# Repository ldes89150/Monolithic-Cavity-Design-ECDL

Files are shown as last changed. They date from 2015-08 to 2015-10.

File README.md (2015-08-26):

# Monolisthic-Cavity-Design-ECDL

## Part Serial numbers
- Grating: [GH13-18V](http://www.thorlabs.de/thorproduct.cfm?partnumber=GH13-18V)
- Collimation Package: [LT110P-B](http://www.thorlabs.de/thorproduct.cfm?partnumber=LT110P-B), [LT220P-B](http://www.thorlabs.de/thorproduct.cfm?partnumber=LT220P-B)
- Socket: [STO5S](http://www.thorlabs.de/thorproduct.cfm?partnumber=STO5S)

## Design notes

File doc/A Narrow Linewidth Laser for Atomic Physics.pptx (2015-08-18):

## A Narrow Linewidth Laser for Atomic Physics

Chung You Shih
Advisor: Dr. Ming-Shien Chang

## Outline

Introduction
Design
Measurement
Frequency locking
Conclusion & Future Work

## Introduction to ECDL

What is ?

E

C

D

L

xternal

avity

iode

aser

## Diode Laser for Atomic Physics

Pros
Cons
high efficiency
compact
inexpensive
wider linewidth
almost maintenance-free
Very stable

## External Cavity

- select central frequency

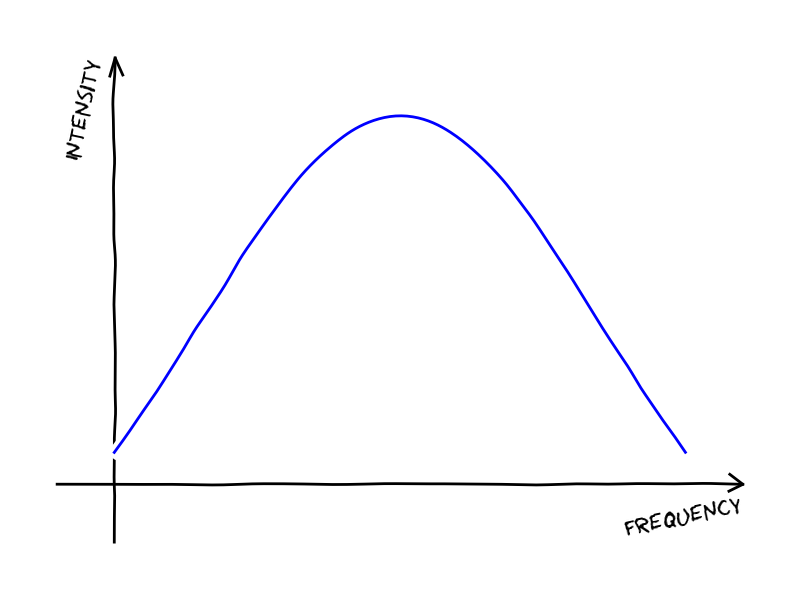
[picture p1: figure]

Δν_(laser)

ν

Narrow laser linewidth

Surface Grating

Volume Holography Grating

Color Filter

Schawlow-Townes Linewidth:
Δν_(laser) =(hν(1+α^2 )l_(tot) T_(oc))/(4πT_(rt)^2 P_(out))

## Purpose – Cold Atom Physics

- Probe atoms
- laser cooling
- Coherent control on atomic states
- optical trap (detuned)

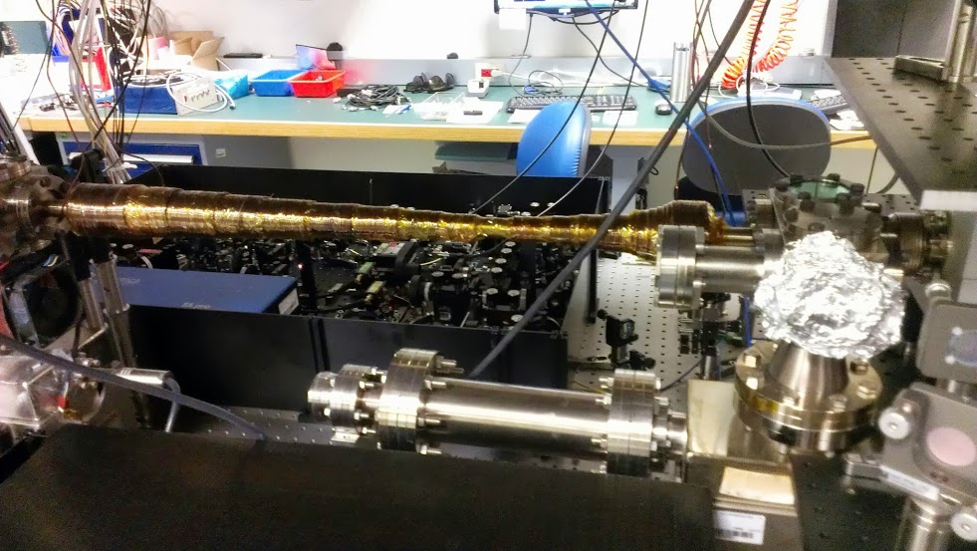
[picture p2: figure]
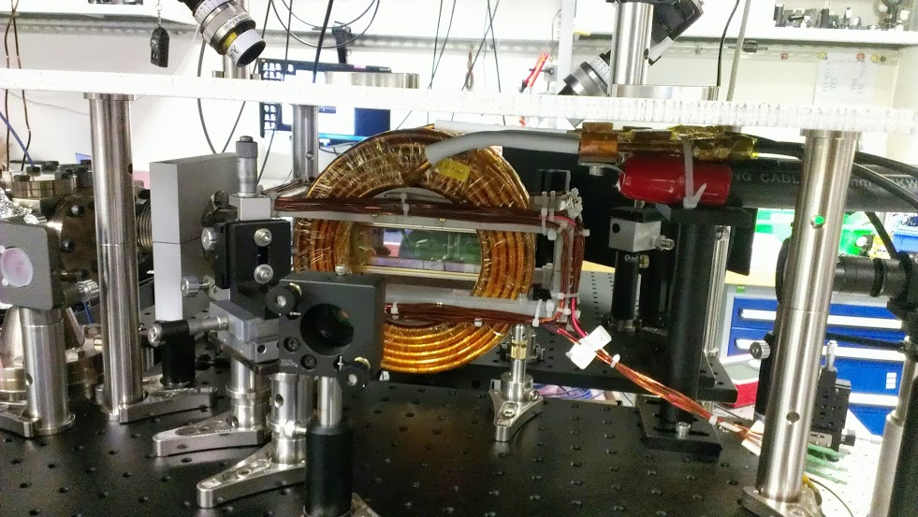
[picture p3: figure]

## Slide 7

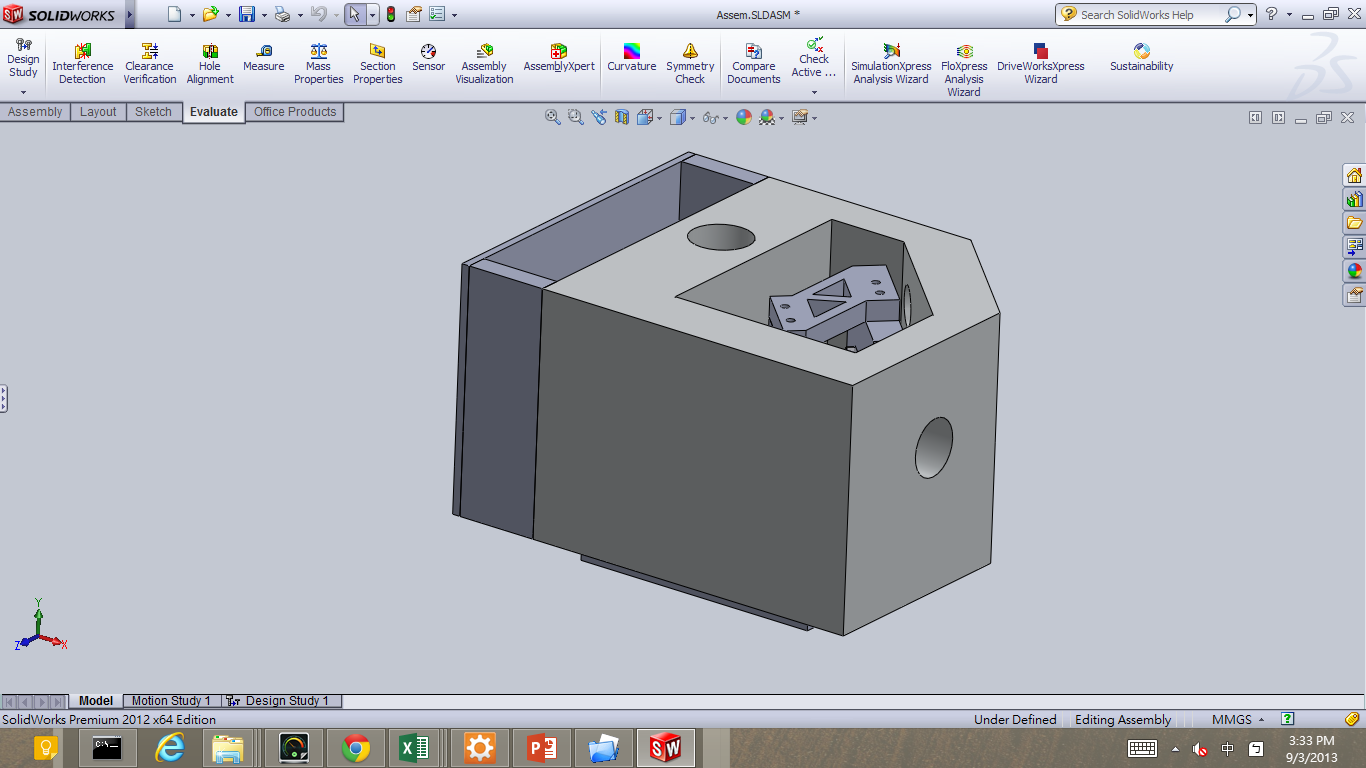
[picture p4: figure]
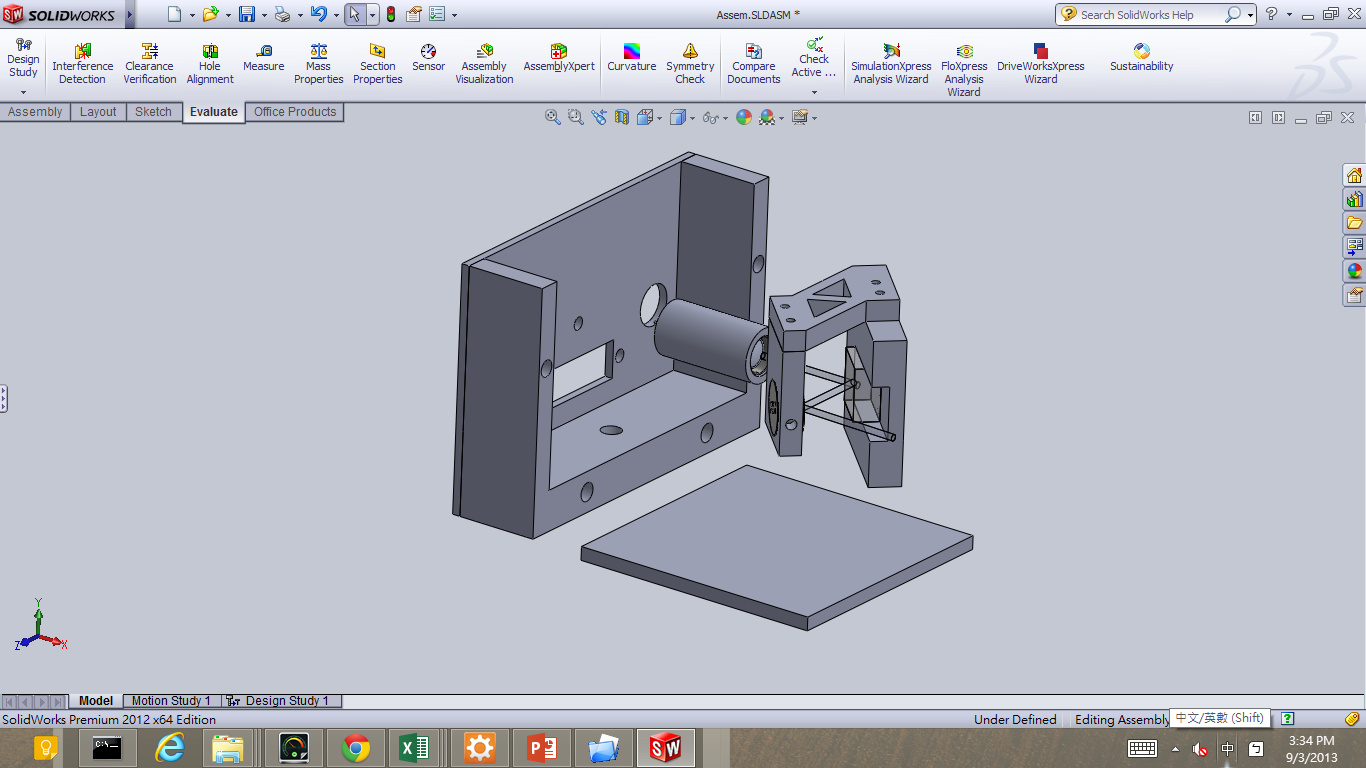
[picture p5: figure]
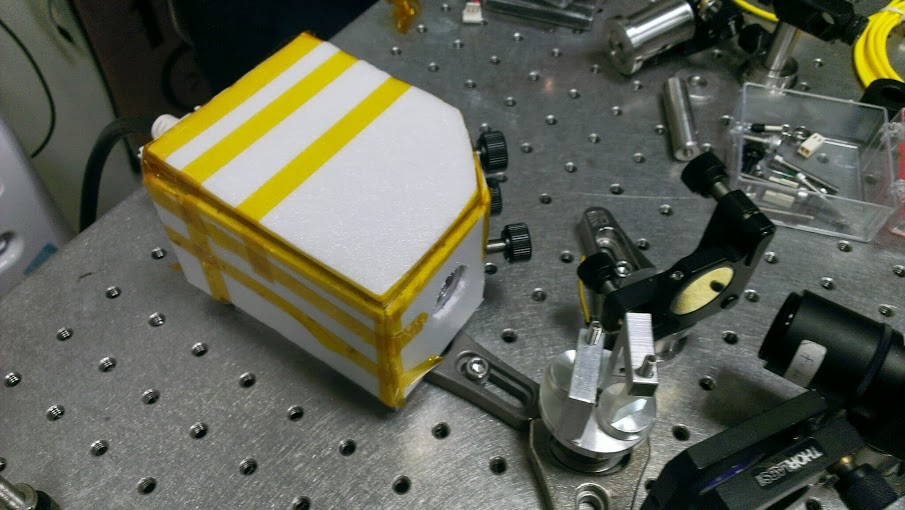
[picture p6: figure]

Idea: Monolithic cavity design
1.high heat capacity
2.good heat conductivity
- temperature control
Mechanical Stability

## Littrow configuration

The grating is always parallel to the mirror.
- No angle shift
Δx=2lΔθ

- Grating equation:
- d(sinα+sinβ)=mλ

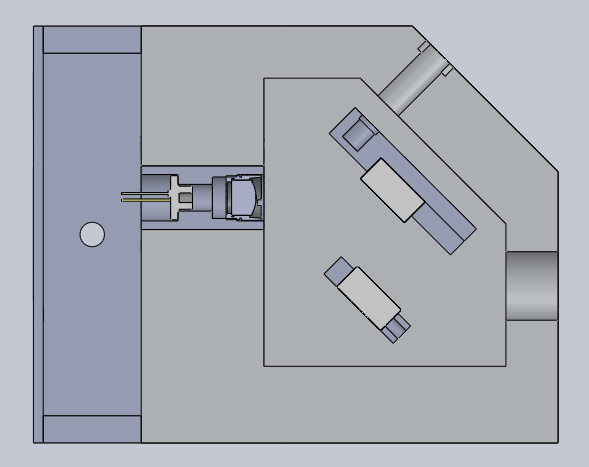
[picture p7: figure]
畫面剪輯

m=1
optical feed back

m=0
beam output

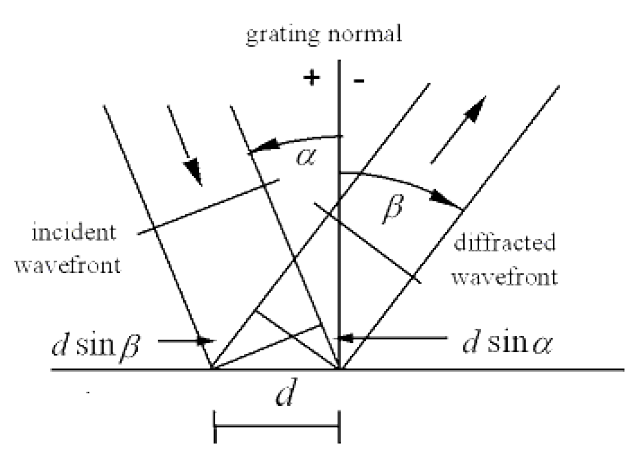
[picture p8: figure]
畫面剪輯

m=1, α=β for optical feed back
2dsinα=λ

2×(1mm)/1800×sinα=1×780.25nm
α=44.606°

m=0 for beam output
α=−β (law of reflection)

## Threshold Current

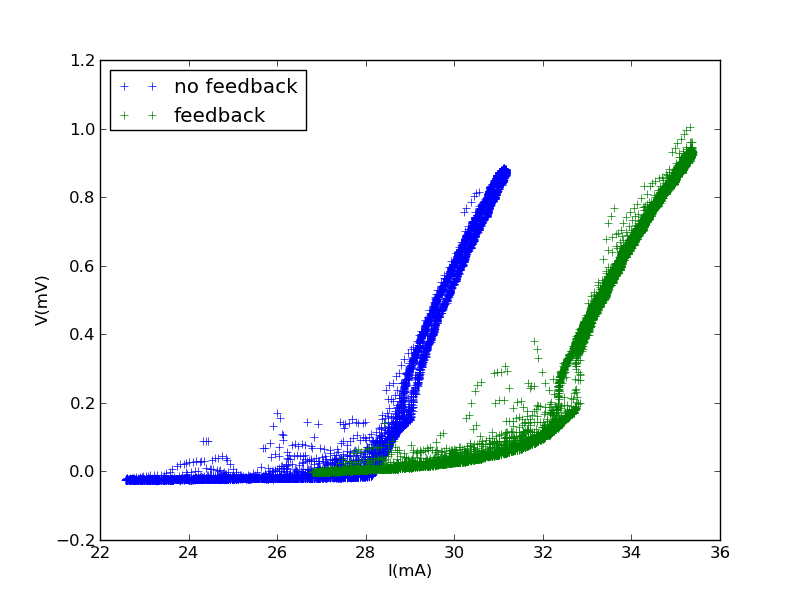
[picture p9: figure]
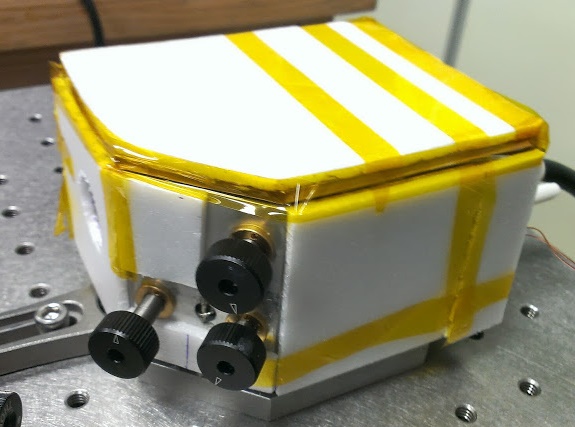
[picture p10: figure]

## Free running

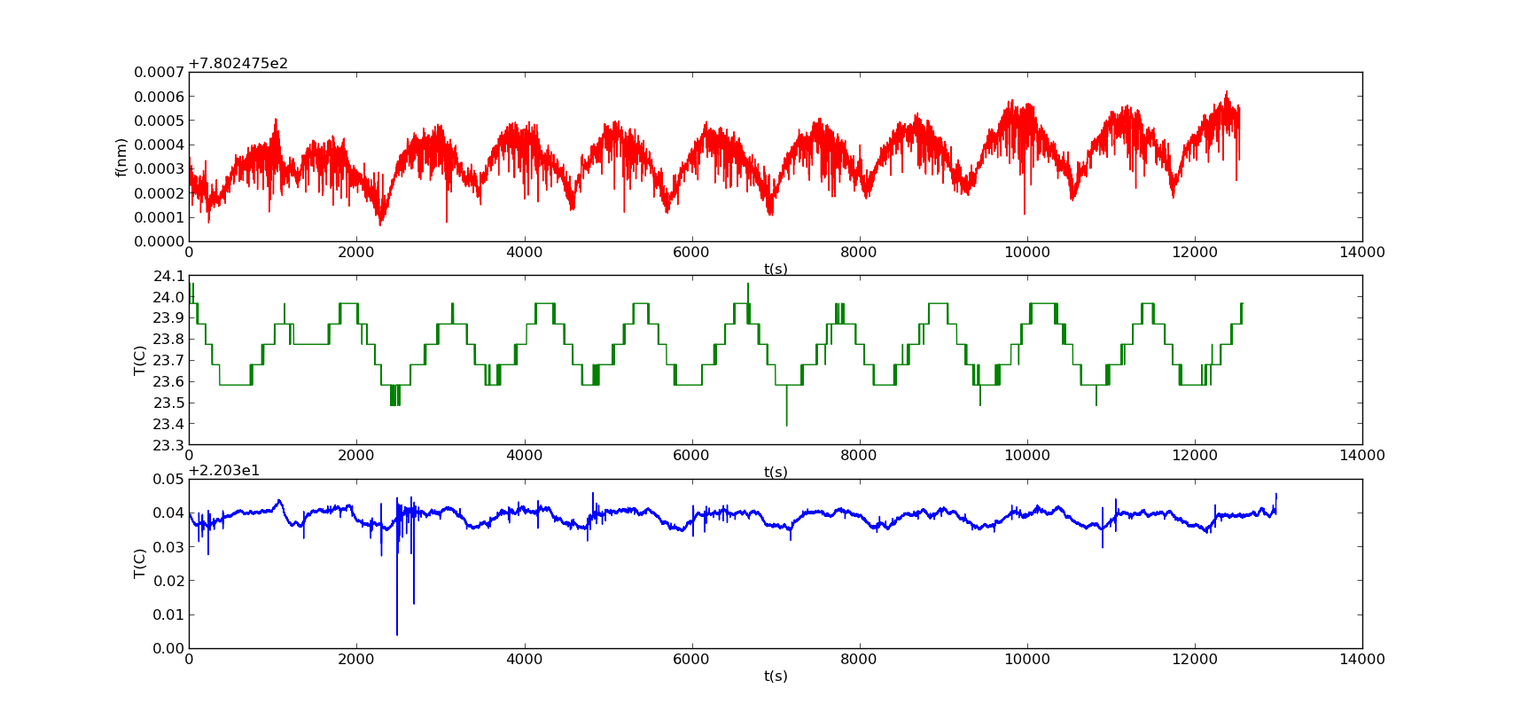
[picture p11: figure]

the same period

<10mk

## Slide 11

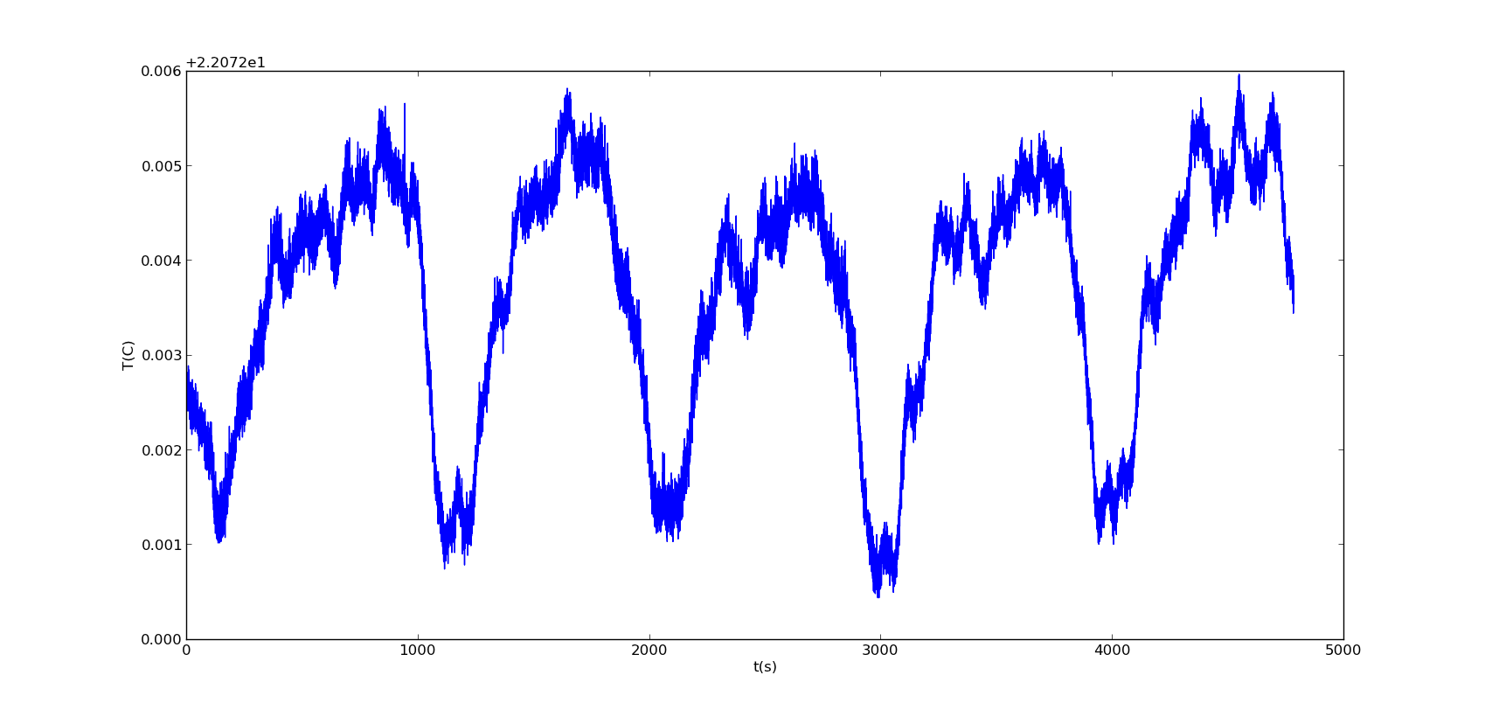
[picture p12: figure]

<5mk

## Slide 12

Lock-in-Amplifier

PD

PBS

250kHz

PID

λ /2

optical isolator

coil

ECDL

wave meter

λ /4

vapor cell

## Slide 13

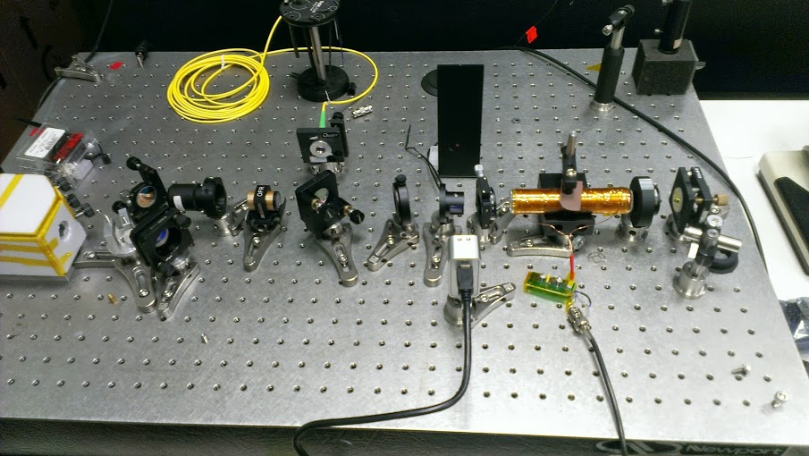
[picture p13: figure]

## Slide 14

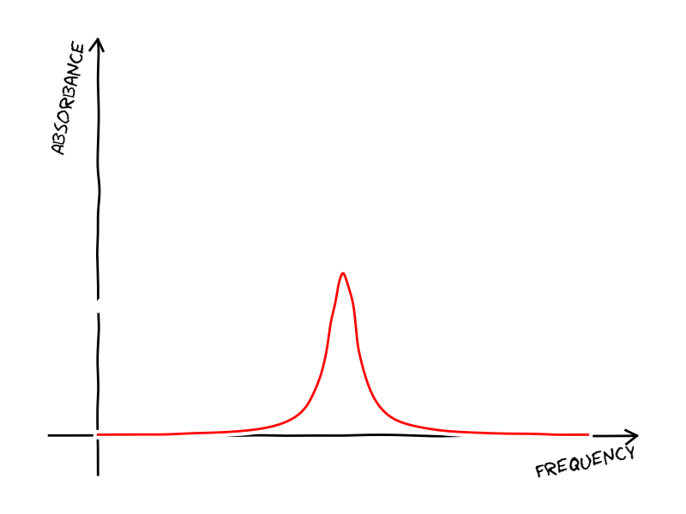
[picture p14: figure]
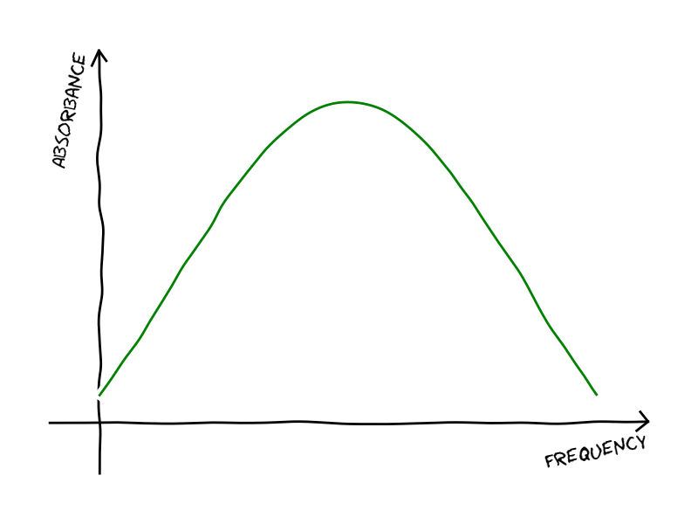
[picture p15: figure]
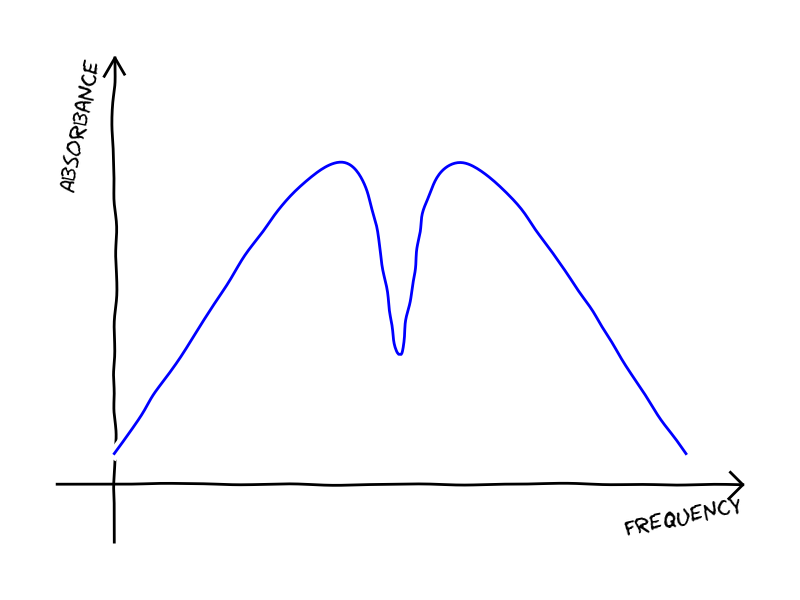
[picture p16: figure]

vz=0

Nature
(Lorentzian)

Negative

Doppler Borden
(Gaussian)

Positive

vapor cell

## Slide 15

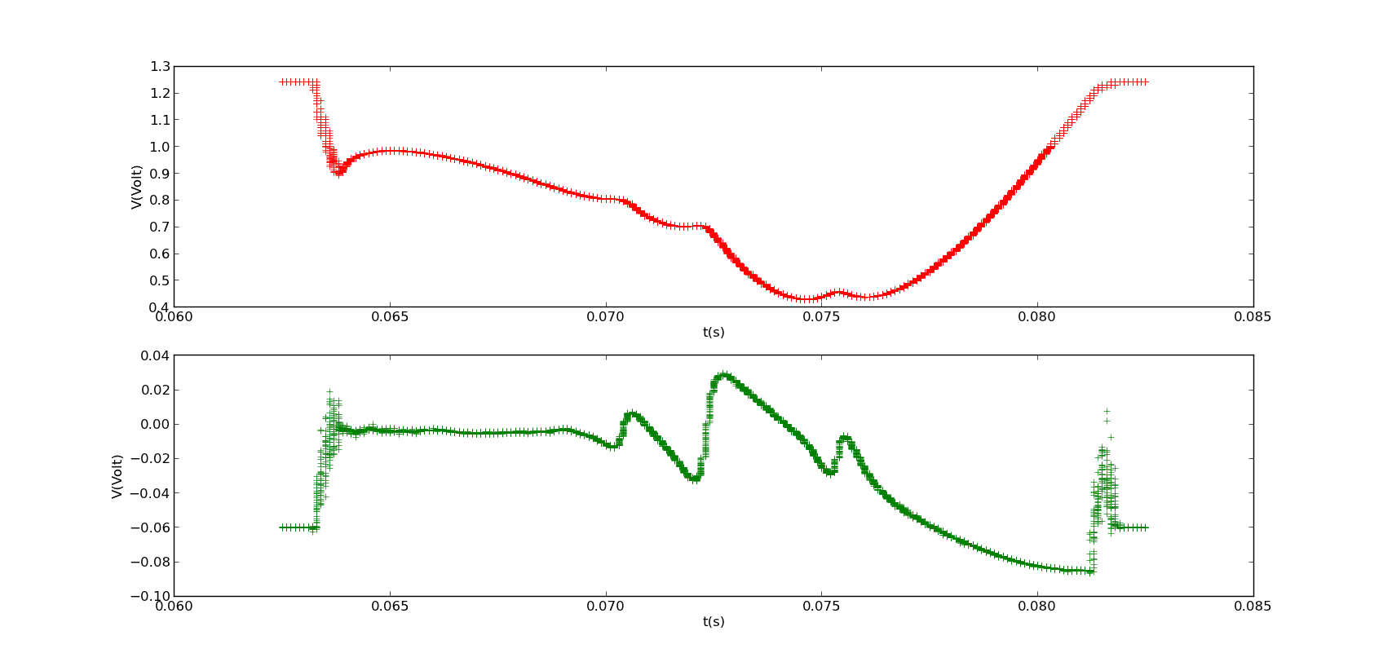
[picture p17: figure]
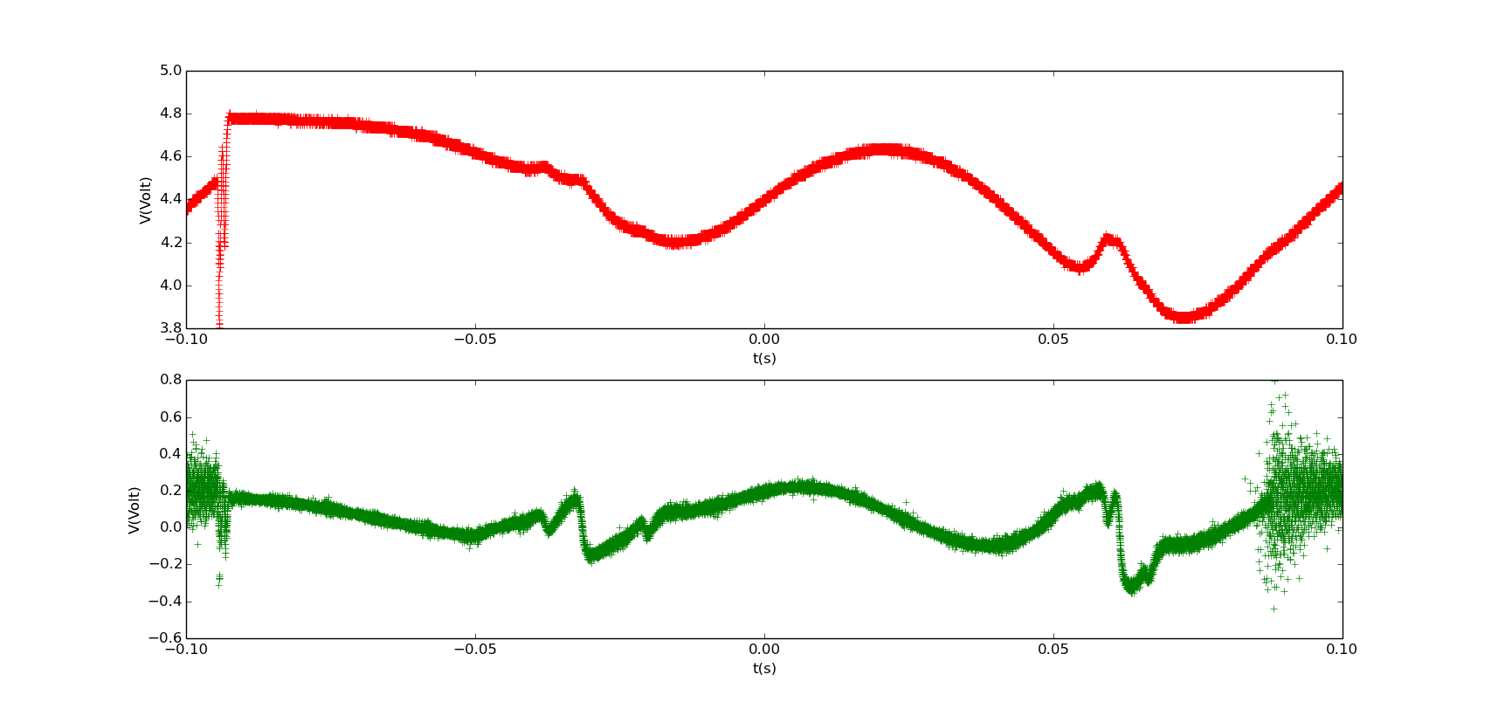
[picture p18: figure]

Rb-87 D2 Line

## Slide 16

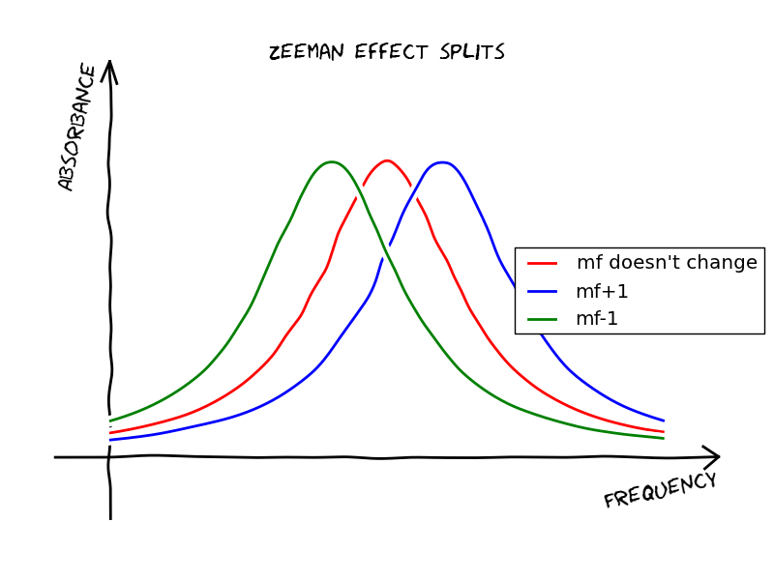
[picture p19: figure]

vapor cell

Linear

λ /4

Circular

degenerate
→2F+1 sublevels

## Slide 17

- frequency:ν=ν_L +ν_m cosωt
- V(ν_L +ν_m cosωt)≈V(ν_L )+((∂V)/(∂ν))_(ν_L) ν_m cosωt
- Lock-in Amplifier: Multiplier + Low Pass Filter
- ∫ (V(ν_L )+((∂V)/(∂ν))_(ν_L) ν_m cosωt)×Kcosωt dt=K/2((∂V)/(∂ν))_(ν_L) ν_m

Lock-in-Amplifier

PID

250kHz

vapor cell

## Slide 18

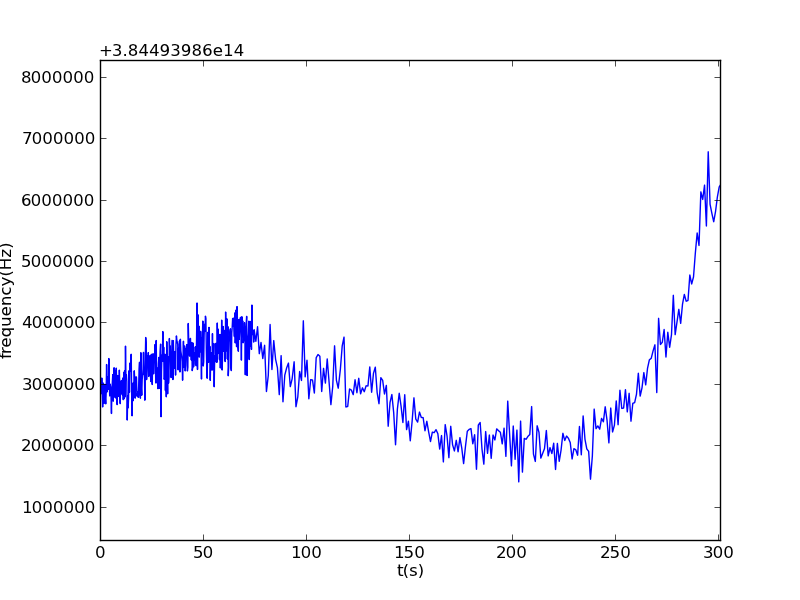
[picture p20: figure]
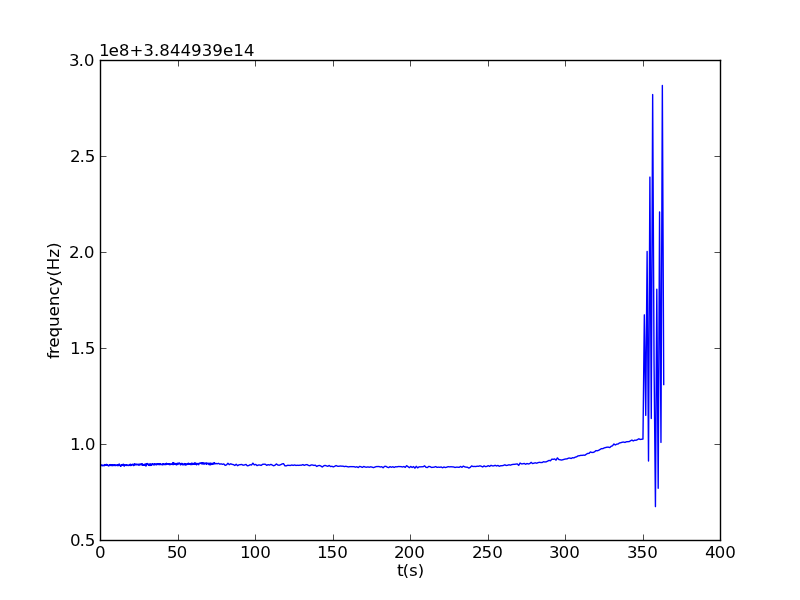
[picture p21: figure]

<3MHz

## Conclusion

- Monolithic cavity design
- Laser stability study
- Saturation spectroscopy
- Laser frequency stabilization

## Future Work

- Linewidth measurement
- Frequency locking optimization
- Laser cooling

## Acknowledgement

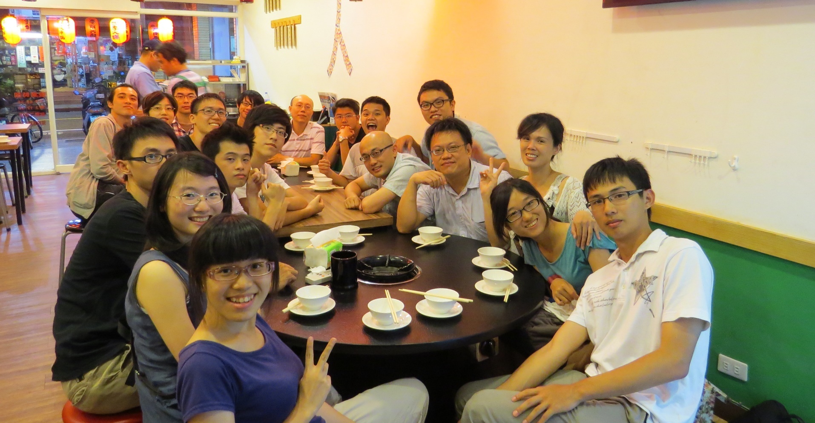
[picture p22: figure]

Lab 107 &
Dr. Ming-Shien Chang

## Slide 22

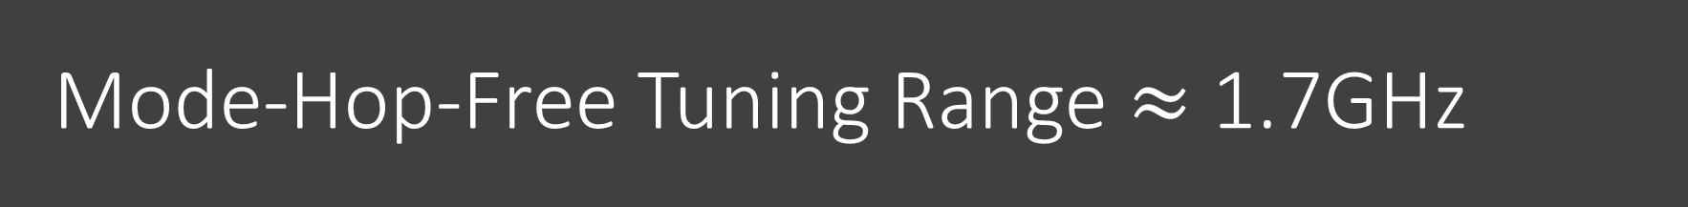
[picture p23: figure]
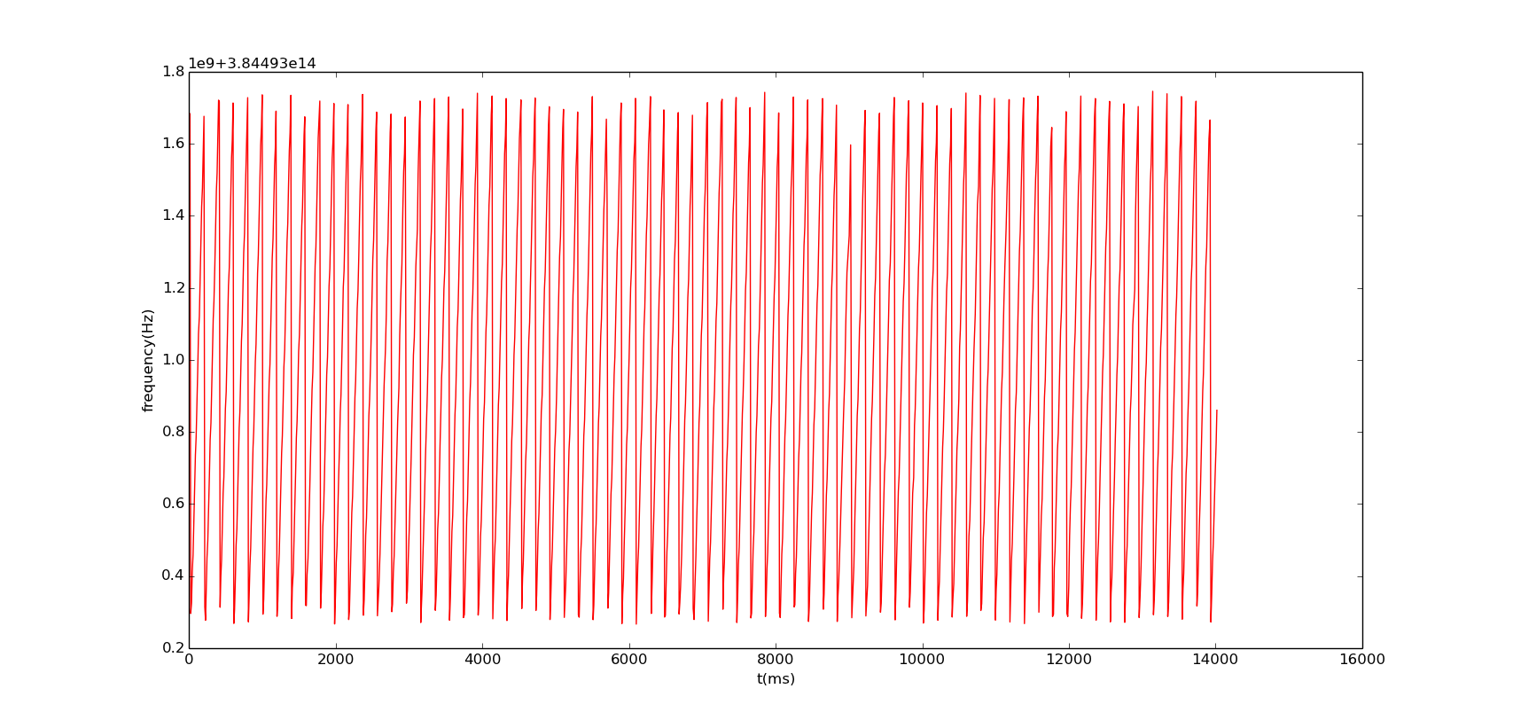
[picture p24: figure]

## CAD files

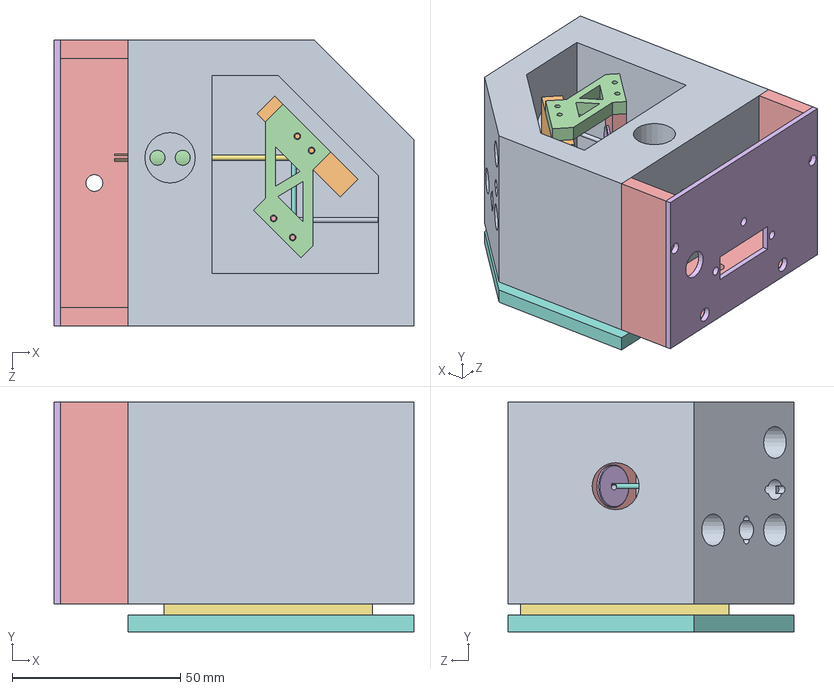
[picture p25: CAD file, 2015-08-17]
Assem.SLDASM
107.0 x 68.3 x 85.0 mm
mirror mount part
GR13-1208-Solidworks
arm part1
arm part2
BB05-E03-Solidworks
laser1
laser2
laser3
diode
C220TME-B-Solidworks
colimation tube final ver2
back
plate
TEC

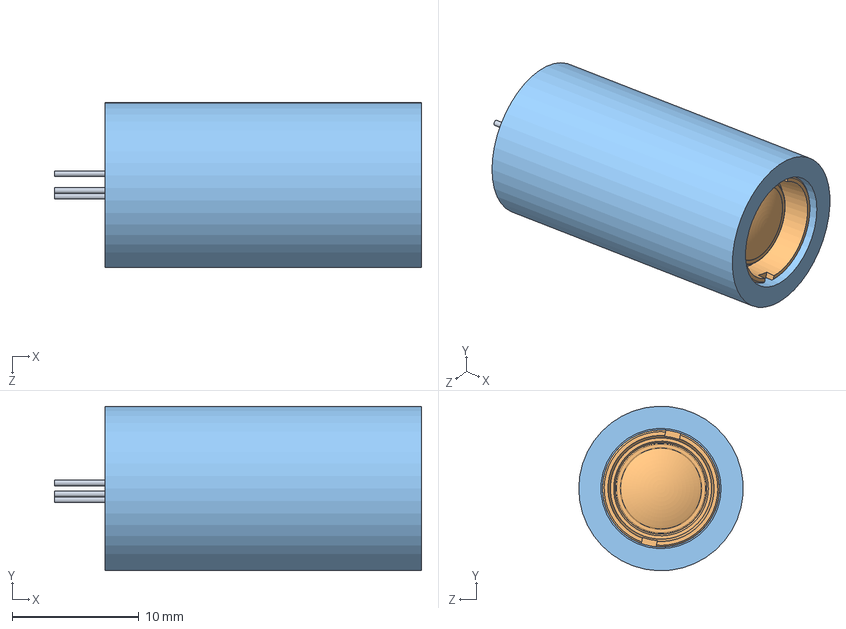
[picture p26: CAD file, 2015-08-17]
colimation tube assembly final.SLDASM
29.0 x 13.0 x 13.0 mm
diode
C220TME-B-Solidworks
colimation tube final ver2

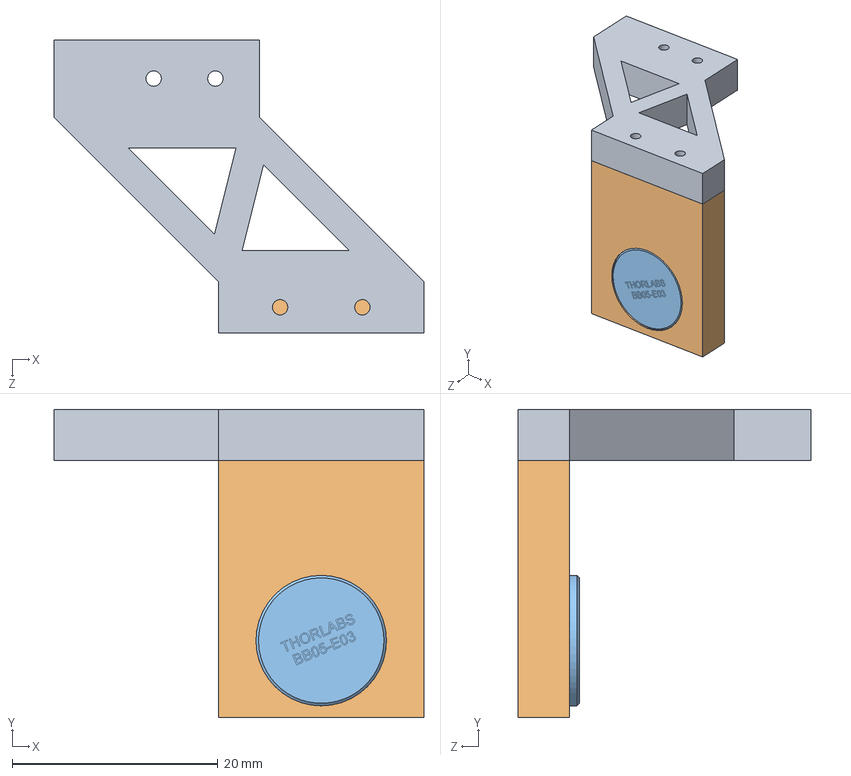
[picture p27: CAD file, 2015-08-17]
arm.SLDASM
36.0 x 30.0 x 28.5 mm
arm part1
arm part2
BB05-E03-Solidworks

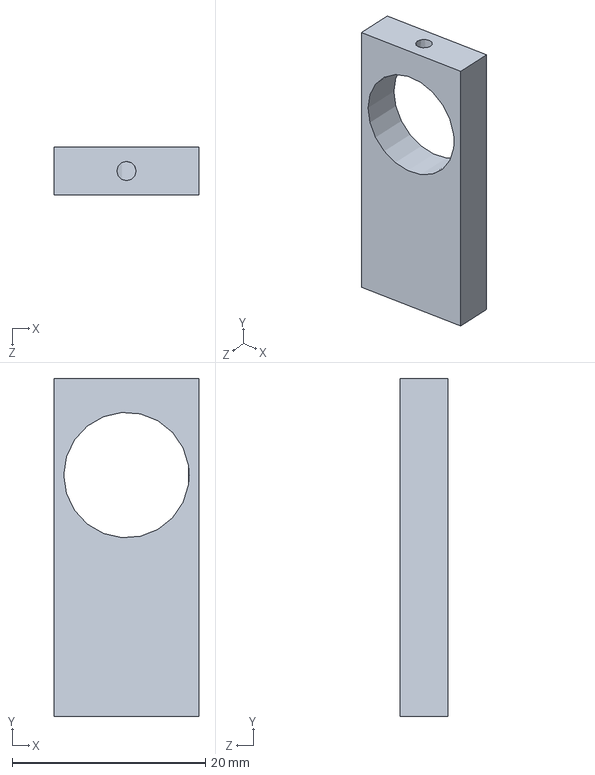
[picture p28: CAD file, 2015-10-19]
filter holder.SLDPRT
15.0 x 35.0 x 5.00 mm

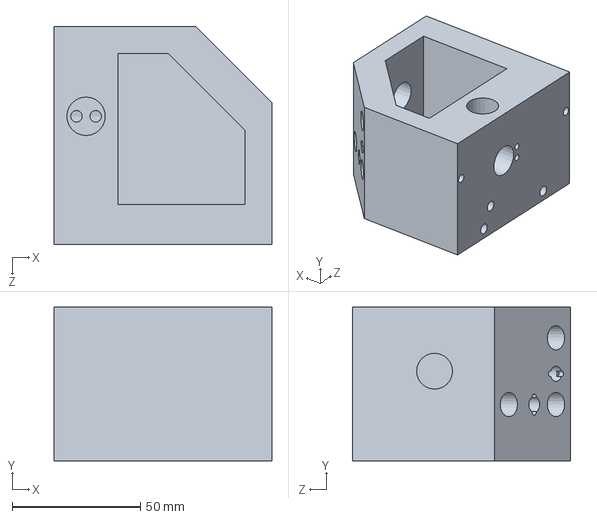
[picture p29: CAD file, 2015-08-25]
box 1.5.SLDPRT
85.0 x 60.0 x 85.0 mm

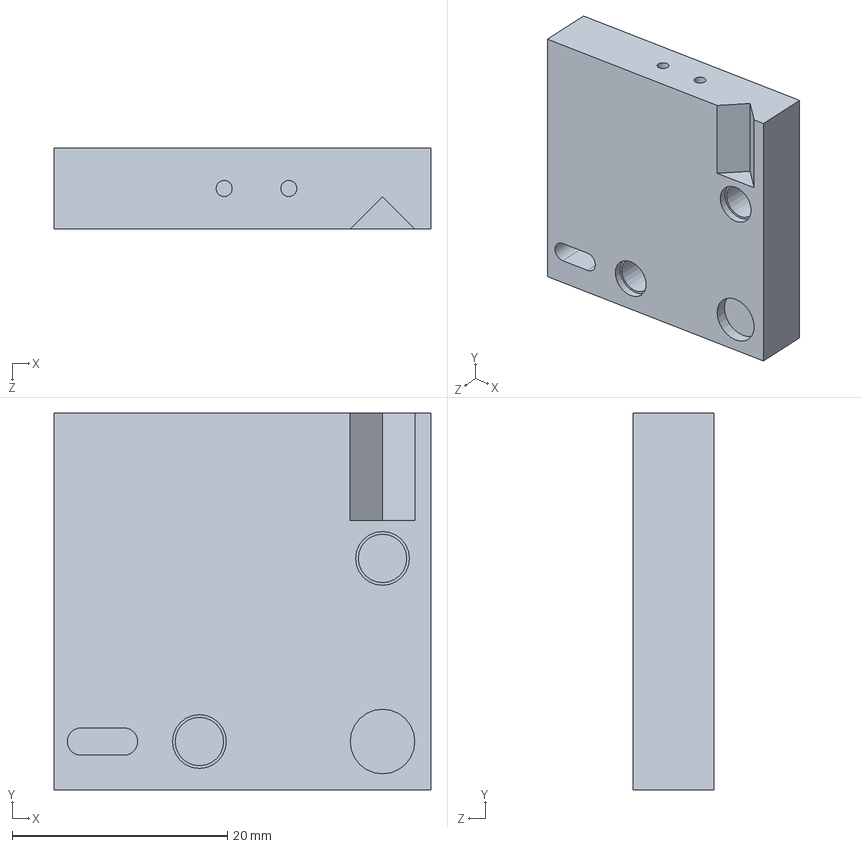
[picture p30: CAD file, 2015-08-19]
mirror mount part.SLDPRT
35.0 x 35.0 x 7.50 mm

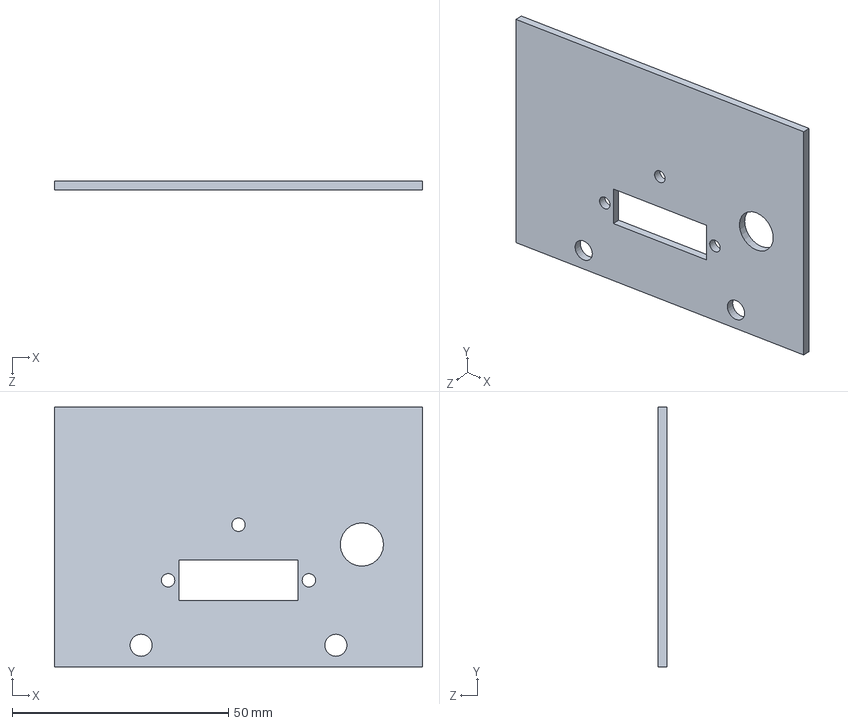
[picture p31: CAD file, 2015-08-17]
plate.SLDPRT
85.0 x 60.0 x 2.00 mm

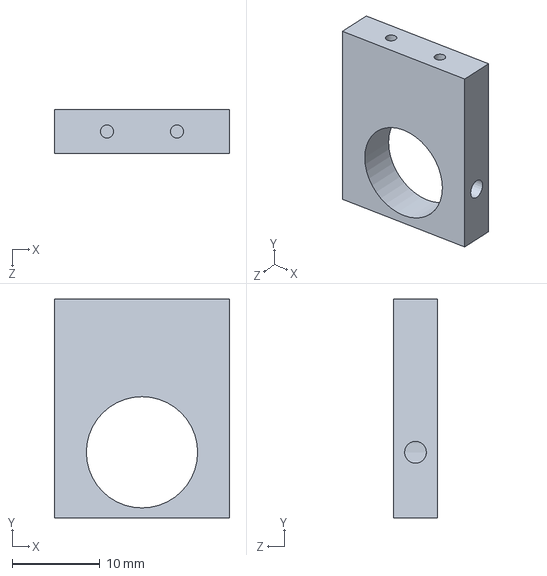
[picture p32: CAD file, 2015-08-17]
arm part2.SLDPRT
20.0 x 25.0 x 5.00 mm

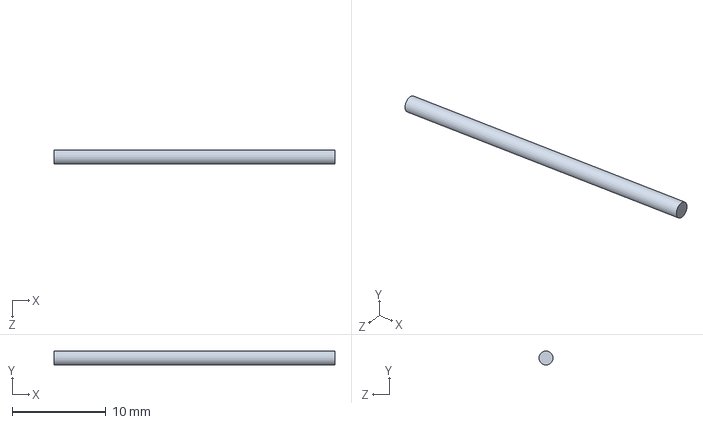
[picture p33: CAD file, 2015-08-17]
laser2.SLDPRT
30.0 x 1.50 x 1.50 mm

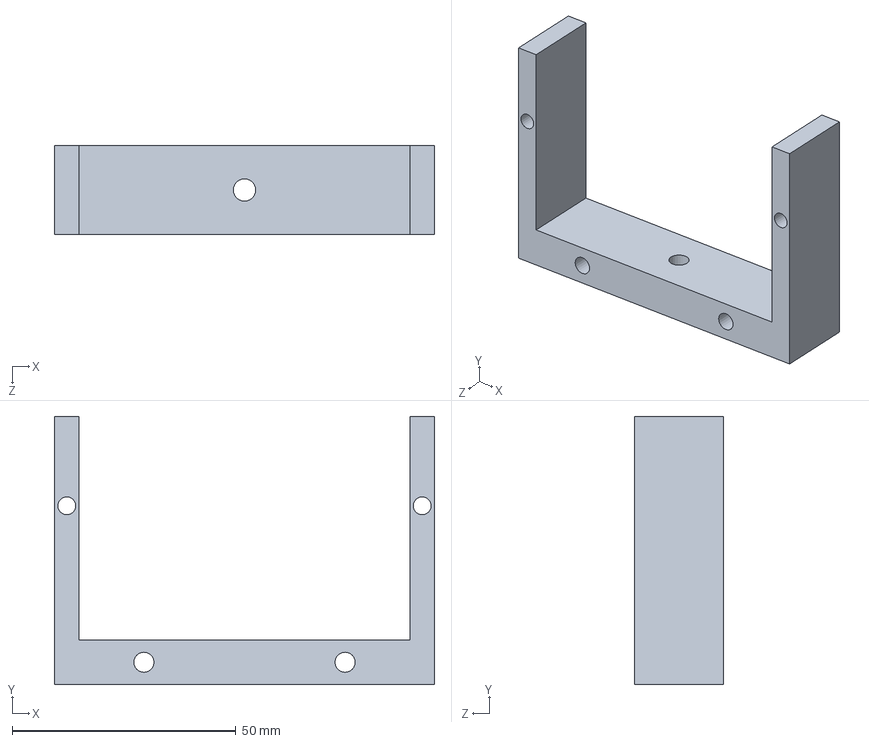
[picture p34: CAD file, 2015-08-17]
back.SLDPRT
85.0 x 60.0 x 20.0 mm

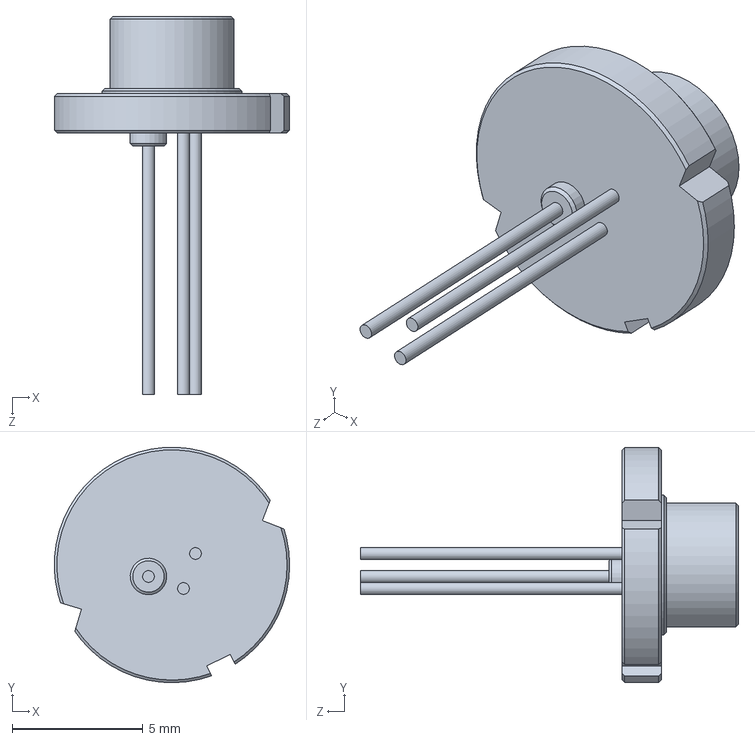
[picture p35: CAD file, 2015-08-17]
diode.SLDPRT
9.00 x 9.00 x 14.4 mm

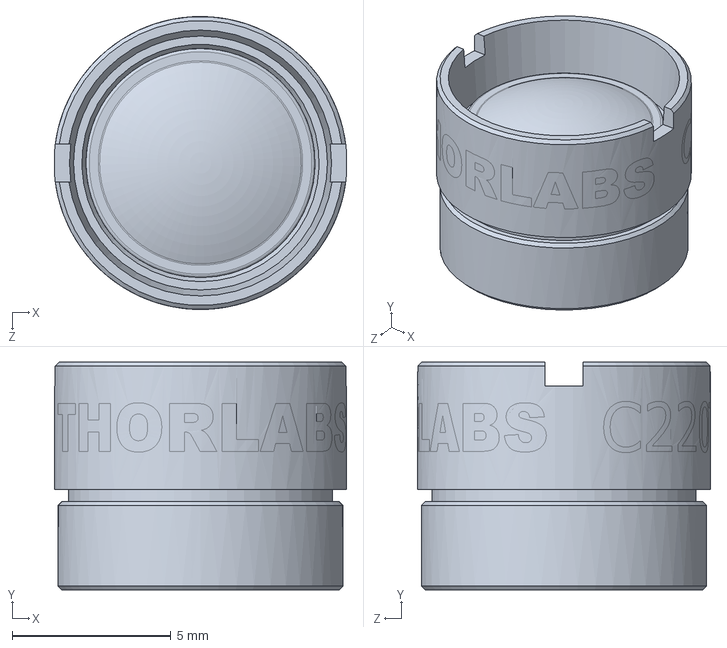
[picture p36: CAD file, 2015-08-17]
C220TME-B-Solidworks.sldprt
9.22 x 7.19 x 9.24 mm

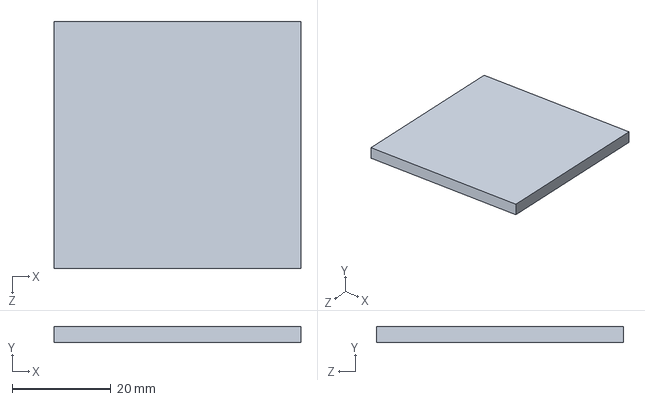
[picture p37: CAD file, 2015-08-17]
TEC.SLDPRT
50.0 x 3.30 x 50.0 mm

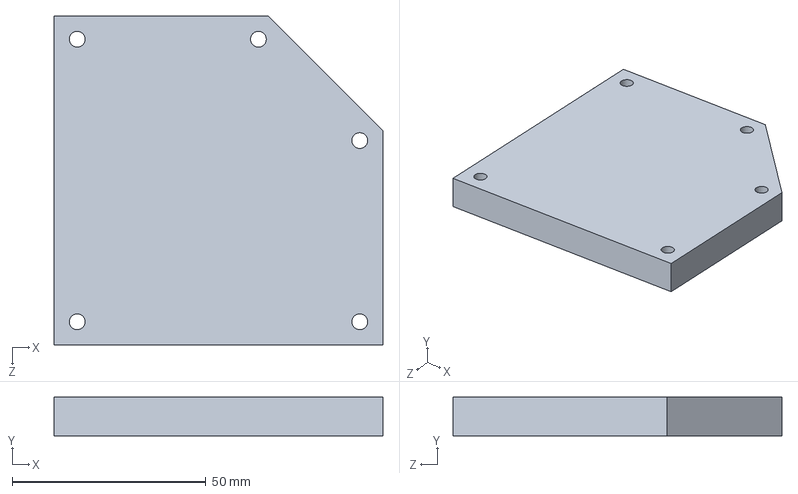
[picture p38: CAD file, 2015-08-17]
bottom.SLDPRT
85.0 x 10.0 x 85.0 mm

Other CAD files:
laser3.SLDPRT
GR13-1208-Solidworks.sldprt
arm part1.SLDPRT
laser1.SLDPRT
BB05-E03-Solidworks.sldprt
colimation tube final ver2.SLDPRT
drawing/arm part1.SLDDRW
drawing/arm part2.SLDDRW
drawing/back.SLDDRW
drawing/bottom.SLDDRW
drawing/box.SLDDRW
drawing/box2.SLDDRW
drawing/colimation tube.SLDDRW
drawing/filter holder.SLDDRW
drawing/mirror mount.SLDDRW
drawing/plate.SLDDRW
top.SLDPRT

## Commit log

2015-08-17 initial commit fork from the version created at 2013
    [Assem.SLDASM, BB05-E03-Solidworks.sldprt, C220TME-B-Solidworks.sldprt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]
2015-08-17 add missing pieces
    [mirror mount.SLDDRW]
2015-08-17 rename the folder to prevent unexpected behavior from solidwork
    [arm part1.SLDDRW, arm part2.SLDDRW, back.SLDDRW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]
2015-08-17 several improvements: - replace the cylindrical halls with V grooves in order to improve the mechanical stability - slightly adjust the holder for gratings - adjust the shape and the depth of the hal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
    [mirror mount part.SLDPRT]
2015-08-19 slightly adjust the position of the screw and some design
    [mirror mount part.SLDPRT]
2015-08-19 slightly adjust the position of the screw and update the drawing
    [mirror mount part.SLDPRT, mirror mount.SLDDRW]
2015-08-25 use the thorlab's collimation tube rather than a custom one
    [box 1.5.SLDPRT, box.SLDDRW]
2015-10-19 add filter holder
    [filter holder.SLDDRW, filter holder.SLDPRT]
